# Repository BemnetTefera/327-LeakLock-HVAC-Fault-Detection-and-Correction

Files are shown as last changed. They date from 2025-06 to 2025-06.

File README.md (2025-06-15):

# LeakLock – Smart HVAC Fault Detection & Correction System

**LeakLock** is a low-cost, real-time HVAC monitoring solution that detects air duct leaks and corrects airflow across a three-zone system. Built with an ESP32, distributed sensors, and a web interface, it combines embedded systems, IoT, and sustainable design principles to solve a real-world energy efficiency problem.

---


# 📄 [Full Design Description (Click Here)](description.md)

## 🔧 Features

- 📶 Wi-Fi-enabled ESP32 microcontroller
- 🌡️ Real-time temperature and pressure sensing
- 🌀 Dual fan and motorized damper control
- 🖥️ Custom web interface using HTML, CSS, and JavaScript
- 🔄 OTA (Over-the-Air) updates for remote firmware management
- 🧩 PCB design files for sensor integration
- 📦 Total cost under $50

---

## 📁 Repository Structure

| File/Folder | Description |
|---|---|
| `index.html` | Web interface frontend |
| `style.css` | Styling for the frontend |
| `server.py` | Tornado-based WebSocket server backend |
| `main.cpp` | ESP32 firmware: sensor reading & motor control |
| `wifi_manager.cpp/h` | Wi-Fi connection handler |
| `sensor_final_v1.brd` | PCB board layout (EAGLE) |
| `sensor_final_v1.sch` | PCB schematic (EAGLE) |
| `README.md` | This file 📄 |

---

## ⚙️ How It Works

1. Sensors collect pressure and temperature data from three duct zones.
2. ESP32 processes this data and communicates with a web dashboard over Wi-Fi.
3. Based on detected anomalies (e.g., pressure drop), the system adjusts fans and damper positions to maintain balance.
4. The user can monitor and override controls via the web interface.
5. Updates can be deployed remotely via OTA.

---

## 🚀 Requirements

- ESP32 Dev Module
- TMP102 Temperature Sensor(s)
- LPS25HB Pressure Sensor(s)
- TB6612FNG Dual H-Bridge Motor Driver
- Servo Motor (for damper control)
- 3D-printed or physical duct model (optional)
- Tornado (Python backend)
- EAGLE (for PCB design)

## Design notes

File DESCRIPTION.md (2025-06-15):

# LeakLock: HVAC Fault Detection and Correction System

**Northwestern University**  
**Department of Electrical and Computer Engineering**  
**ELEC_ENG 327: Electronic System Design II**  
**Project Report by Bemnet Tefera – May 2025**

---

## 📑 Table of Contents

1. [Abstract](#abstract)  
2. [Introduction](#introduction)  
3. [Design Requirements and Constraints](#design-requirements-and-constraints)  
4. [Engineering Standards](#engineering-standards)  
5. [Broader Considerations](#broader-considerations)  
6. [Design Description](#design-description)  
   - [System Overview](#system-overview)  
   - [Block Diagram](#block-diagram)  
   - [Firmware and Code](#firmware-and-code)  
   - [3D Printing](#3d-printing)  
   - [PCB Design](#pcb-design)  
7. [Final Product](#final-product)  
8. [Performance and Limitations](#performance-and-limitations)  
9. [Challenges Encountered](#challenges-encountered)  
10. [Planning and Organization](#planning-and-organization)  
11. [Bill of Materials (BOM)](#bill-of-materials-bom)  
12. [Interview Results and Market Research](#interview-results-and-market-research)  
13. [Conclusion](#conclusion)  
14. [References](#references)  

---

## Abstract

LeakLock is a smart, affordable HVAC fault detection system designed to identify duct leaks and airflow inefficiencies in real-time. Built using ESP32 microcontrollers, distributed pressure and temperature sensors, and a web-based dashboard, it enables intelligent zone-based regulation across a three-zone mock HVAC duct. OTA updates, Wi-Fi connectivity, and live dashboard control make it scalable and user-friendly. LeakLock operates under $50 and offers an alternative to expensive commercial systems, making HVAC optimization accessible to both residential and developing regions.

## Introduction

LeakLock aims to solve the often-overlooked problem of HVAC inefficiency due to undetected faults. This embedded system monitors airflow and temperature data, then responds with fan control and damper adjustments to restore balance. The solution uses off-the-shelf hardware and a custom interface built with HTML/CSS/JS, focusing on simplicity and affordability compared to commercial alternatives.

### Problem Statement

HVAC systems lose energy due to hidden inefficiencies like duct leaks and sensor failures. Most current solutions are expensive, require complex setup, and lack real-time response. LeakLock addresses these limitations by offering a modular, responsive, low-cost alternative for multi-zone HVAC diagnostics.

## Design Requirements and Constraints

### Key Requirements
- Multi-zone temperature and pressure monitoring
- Real-time sensor feedback and response
- OTA firmware updates over Wi-Fi
- Live dashboard for monitoring and manual overrides
- Target system cost under $50

### Design Constraints
- Budget limited sensor precision (e.g., low Pa sensitivity in LPS25HB)
- Component integration required space optimization
- I²C channel limits required a multiplexer
- Environmental simulation with 3D printed ducts lacked real-world turbulence/humidity

## Engineering Standards

- Software written in Arduino C++ with modular FreeRTOS tasks
- Sensors used I²C protocol, communication handled via WebSocket (RFC 6455)
- PCB followed best practices in bypassing, grounding, and 3.3V regulation
- Fail-safes included timeout-based actuator shutdowns and startup defaults

## Broader Considerations

LeakLock's accessibility has wide-reaching implications for energy conservation, especially in underserved regions. Its privacy-respecting local data use and intuitive UI encourage widespread adoption. Future improvements could include encryption and authentication for remote access.

## Design Description

### System Overview
- TMP102 (Temp), LPS25HB (Pressure), 5V fans, servos per zone
- ESP32 Wroom-32E controls each zone, communicates via WebSockets
- Web UI supports 3D HVAC model and manual control

### Block Diagram


### Firmware and Code
- Structured around FreeRTOS for modular tasking
- Handles sensor reads, UI communication, actuator control, OTA updates
- Uses TCA I²C MUX to manage multiple sensors per board

### 3D Printing
LeakLock uses a T-shaped 3D printed duct system sealed with aluminum tape to simulate real HVAC airflow. It allows testing of backpressure effects and zone control but lacks full thermal or turbulent fidelity.




### PCB Design
Two iterations were produced:
1. Breakout + breadboard with separate ESP32 (60x70mm)
2. Final compact board (45x50mm) with integrated microcontroller, motor driver, MUX, and indicator LEDs
------------------------------------------------------------------------------------------------------------------------------------------------------
### Final Iteration of Manufatured PCB
<div style="display: flex; gap: 10px;">
  3D Printed Duct 2
   3D Printed Duct 1
</div>
-------------------------------------------------------------------------------------------------------------------------------------------------------

## Final Product

### Initial Goal vs Final Product
- Retained core goal of <$50 cost per module (actual: $16.35)
- UI moved from 3D model to reliable data display
- Dampers functional but not mechanically integrated due to fit challenges
- RTOS replaced loop-based firmware for better parallelism

### Initial Loop based Architecture


### Improved Real Time Operating System Flow


### Final User interface


## Performance and Limitations

- System latency: <150ms round trip
- FreeRTOS improved responsiveness and multitasking
- Sensor precision limited by hardware
- UI does not currently support trend logging or analytics

## Challenges Encountered

- Mechanical issues with damper integration in 3D duct
- ML model failed due to lack of labeled datasets (43.6% error)
- I²C misreads from misinterpreting 16-bit register format
- Early complexity managing multiple sensors and task flows

## Planning and Organization

Project executed over 8 weeks with milestones tracked via Gantt chart. Major tasks included PCB design, mechanical build, UI development, and firmware migration to RTOS.

## Bill of Materials (BOM)

| Component | Quantity | Unit Price | Total |
|---|---|---|---|
| TB6612FNG H-Bridge | 5 | $1.82 | $9.10 |
| TMP102 Temp Sensor | 12 | $0.69 | $8.28 |
| LPS25HB Pressure Sensor  | 12 | $4.62 | $55.44|
| TCA9548A I²C Mux | 5 | $1.17 | $5.85 |
| Passive Components | — | — | ~$10  |
| **Total Cost (approx.)** | | | **$93.26** |

## Interview Results and Market Research

Professionals and renters alike expressed interest in an affordable, intelligent HVAC tool. Market size expected to reach $479M by 2033. Key interview insights emphasized automation, accessibility, cost-efficiency, and security. LeakLock compares favorably to $500–$2000 commercial competitors like Ecobee, Robinair, and INFICON.

## Conclusion

LeakLock brought together hardware, firmware, UI, and real-world design principles into a system that’s scalable and cost-effective. Despite setbacks like sensor limitations and incomplete ML models, it stands as a robust foundation for future HVAC optimization tools. Future directions include cloud integration, mobile apps, better prediction models, and improved mechanical integration.

## References

- Chvala, W. D. (2021). *Duct leakage in residential homes (FY1024)*. University of Florida IFAS Extension. https://edis.ifas.ufl.edu/publication/FY1024  
- Market Growth Reports (2025). *Leak Detection Equipment Market Forecast*. https://www.marketgrowthreports.com/market-reports/leak-detection-equipment-market-111538

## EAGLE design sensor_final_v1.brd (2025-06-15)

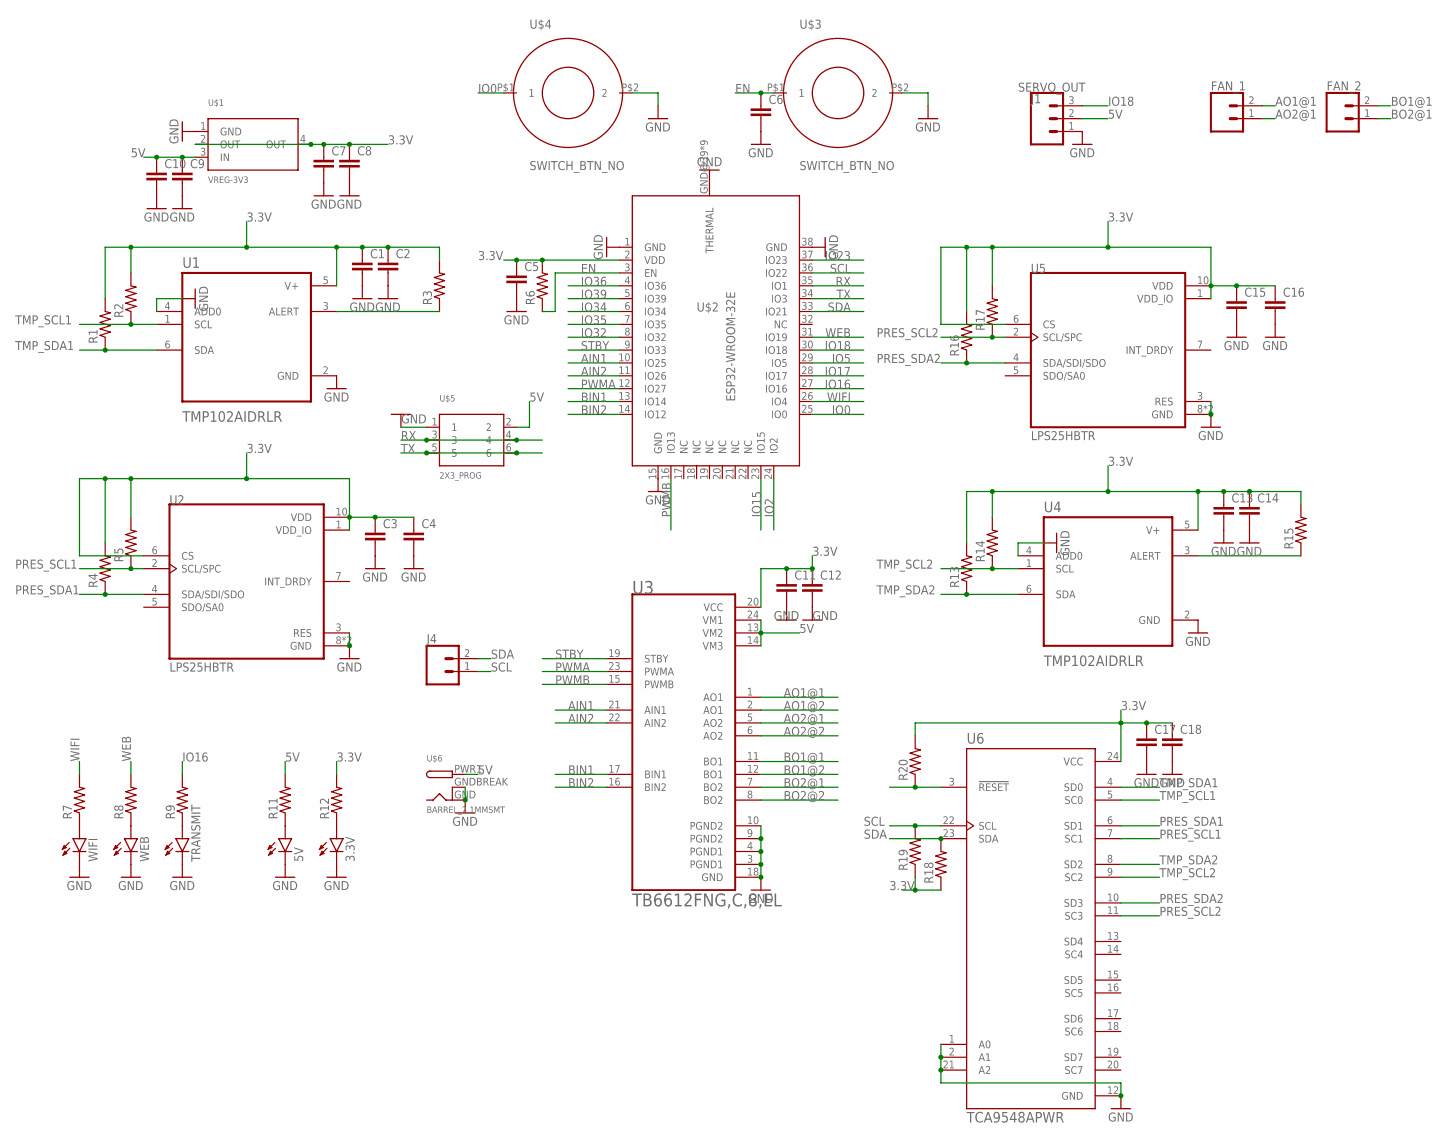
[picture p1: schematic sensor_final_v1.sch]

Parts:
3.3V, 5V: LEDSMT1206; 1206
C1, C2, C3, C4, C5, C6, C7, C8, C9, C10, C11, C12, C13, C14, C15, C16, C17, C18: CAP; 0805
FAN_1, FAN_2: CONN_02; 1X02
J1: SERVO_OUT; 1X03
J4: CONN_02; 1X02
R1, R2, R3, R4, R5, R6, R7, R8, R9, R11, R12, R13, R14, R15, R16, R17, R18, R19, R20: RES; 0805
TRANSMIT: LEDSMT1206; 1206
U1, U4: TMP102AIDRLR; SOT50P160X60-6N
U2, U5: LPS25HBTR; PQFN60P250X250X80-10N
U3: TB6612FNG,C,8,EL; SOP65P760X160-24N
U6: TCA9548APWR; SOP65P640X120-24N
U$1: VREG-3V3; R-PDSO-G4_TI
U$2: ESP32-WROOM-32E
U$3, U$4: SWITCH_BTN_NO; BTN_2
U$5: 2X3_PROG; 2X3_0.1IN
U$6: BARREL_2.1MMSMT; DCJACK_2MM_SMT
WEB: LEDSMT1206; 1206
WIFI: LEDSMT1206; 1206

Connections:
3.3V: C1.1, C2.1, C3.1, C4.1, C5.1, C7.1, C8.1, C11.1, C12.1, C13.1, C14.1, C15.1, C16.1, C17.1, C18.1, R1.2, R2.2, R3.2, R4.2, R5.2, R6.2, R12.2, R13.2, R14.2, R15.2, R16.2, R17.2, R18.1, R19.1, R20.2, U1.5 (V+), U2.1 (VDD_IO), U2.6 (CS), U2.10 (VDD), U3.20 (VCC), U4.5 (V+), U5.1 (VDD_IO), U5.6 (CS), U5.10 (VDD), U6.24 (VCC), U$1.2 (OUT), U$1.4 (OUT), U$2.2 (VDD)
5V: C9.1, C10.1, J1.2, R11.2, U3.13 (VM2), U3.14 (VM3), U3.24 (VM1), U$1.3 (IN), U$5.2, U$6.PWR1 (PWR)
AIN1: U3.21 (AIN1), U$2.10 (IO25)
AIN2: U3.22 (AIN2), U$2.11 (IO26)
AO1@1: FAN_1.2, U3.1 (AO1)
AO1@2: U3.2 (AO1)
AO2@1: FAN_1.1, U3.5 (AO2)
AO2@2: U3.6 (AO2)
BIN1: U3.17 (BIN1), U$2.13 (IO14)
BIN2: U3.16 (BIN2), U$2.14 (IO12)
BO1@1: FAN_2.2, U3.11 (BO1)
BO1@2: U3.12 (BO1)
BO2@1: FAN_2.1, U3.7 (BO2)
BO2@2: U3.8 (BO2)
EN: C6.1, R6.1, U$2.3 (EN), U$3.P$1 (1)
GND: 3.3V.C, 5V.C, C1.2, C2.2, C3.2, C4.2, C5.2, C6.2, C7.2, C8.2, C9.2, C10.2, C11.2, C12.2, C13.2, C14.2, C15.2, C16.2, C17.2, C18.2, J1.1, TRANSMIT.C, U1.2 (GND), U1.4 (ADD0), U2.3 (RES), U2.8 (GND), U2.9 (GND), U3.3 (PGND1), U3.4 (PGND1), U3.9 (PGND2), U3.10 (PGND2), U3.18 (GND), U4.2 (GND), U4.4 (ADD0), U5.3 (RES), U5.8 (GND), U5.9 (GND), U6.1 (A0), U6.2 (A1), U6.12 (GND), U6.21 (A2), U$1.1 (GND), U$2.1 (GND), U$2.15 (GND), U$2.38 (GND), U$2.GND@39 (THERMAL), U$2.GND@40 (THERMAL), U$2.GND@41 (THERMAL), U$2.GND@42 (THERMAL), U$2.GND@43 (THERMAL), U$2.GND@44 (THERMAL), U$2.GND@45 (THERMAL), U$2.GND@46 (THERMAL), U$2.GND@47 (THERMAL), U$3.P$2 (2), U$4.P$2 (2), U$5.1, U$6.GND, U$6.GNDBREAK, WEB.C, WIFI.C
IO0: U$2.25 (IO0), U$4.P$1 (1)
IO2: U$2.24 (IO2)
IO5: U$2.29 (IO5)
IO15: U$2.23 (IO15)
IO16: R9.2, U$2.27 (IO16)
IO17: U$2.28 (IO17)
IO18: J1.3, U$2.30 (IO18)
IO23: U$2.37 (IO23)
IO32: U$2.8 (IO32)
IO34: U$2.6 (IO34)
IO35: U$2.7 (IO35)
IO36: U$2.4 (IO36)
IO39: U$2.5 (IO39)
unnamed: R20.1, U6.3 (!RESET)
unnamed: R3.1, U1.3 (ALERT)
unnamed: R7.1, WIFI.A
unnamed: R8.1, WEB.A
unnamed: R9.1, TRANSMIT.A
unnamed: 5V.A, R11.1
unnamed: 3.3V.A, R12.1
unnamed: R15.1, U4.3 (ALERT)
PRES_SCL1: R5.1, U2.2 (SCL/SPC), U6.7 (SC1)
PRES_SCL2: R17.1, U5.2 (SCL/SPC), U6.11 (SC3)
PRES_SDA1: R4.1, U2.4 (SDA/SDI/SDO), U6.6 (SD1)
PRES_SDA2: R16.1, U5.4 (SDA/SDI/SDO), U6.10 (SD3)
PWMA: U3.23 (PWMA), U$2.12 (IO27)
PWMB: U3.15 (PWMB), U$2.16 (IO13)
RX: U$2.35 (IO1), U$5.3, U$5.4
SCL: J4.1, R19.2, U6.22 (SCL), U$2.36 (IO22)
SDA: J4.2, R18.2, U6.23 (SDA), U$2.33 (IO21)
STBY: U3.19 (STBY), U$2.9 (IO33)
TMP_SCL1: R2.1, U1.1 (SCL), U6.5 (SC0)
TMP_SCL2: R14.1, U4.1 (SCL), U6.9 (SC2)
TMP_SDA1: R1.1, U1.6 (SDA), U6.4 (SD0)
TMP_SDA2: R13.1, U4.6 (SDA), U6.8 (SD2)
TX: U$2.34 (IO3), U$5.5, U$5.6
WEB: R8.2, U$2.31 (IO19)
WIFI: R7.2, U$2.26 (IO4)

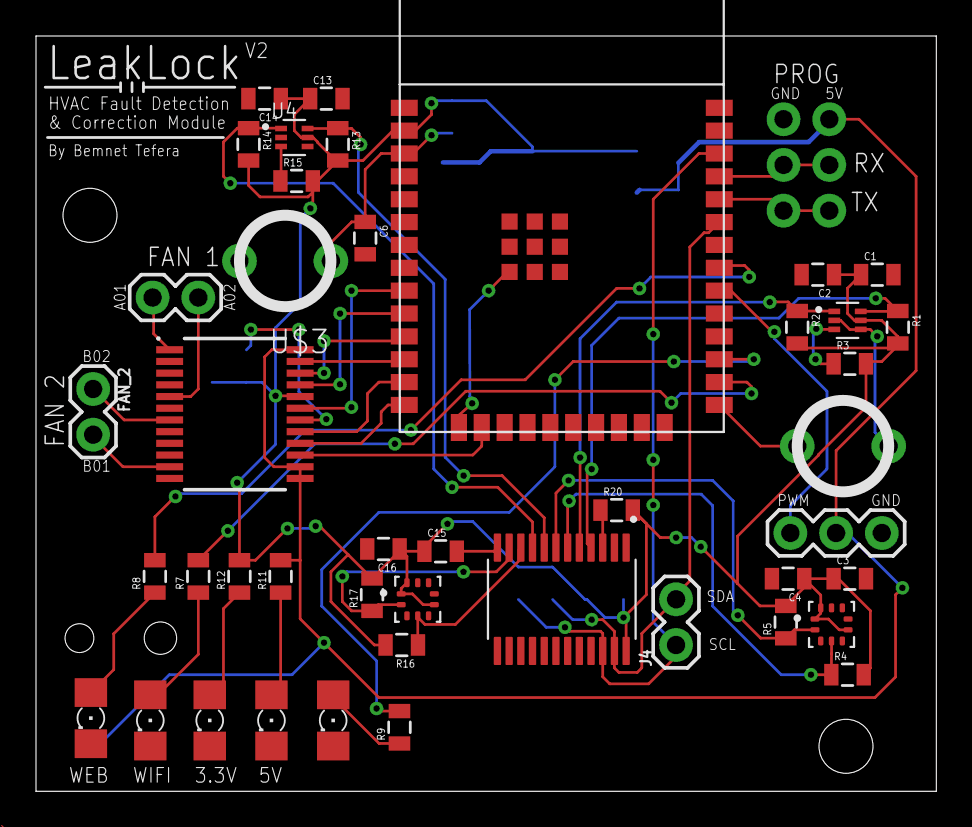
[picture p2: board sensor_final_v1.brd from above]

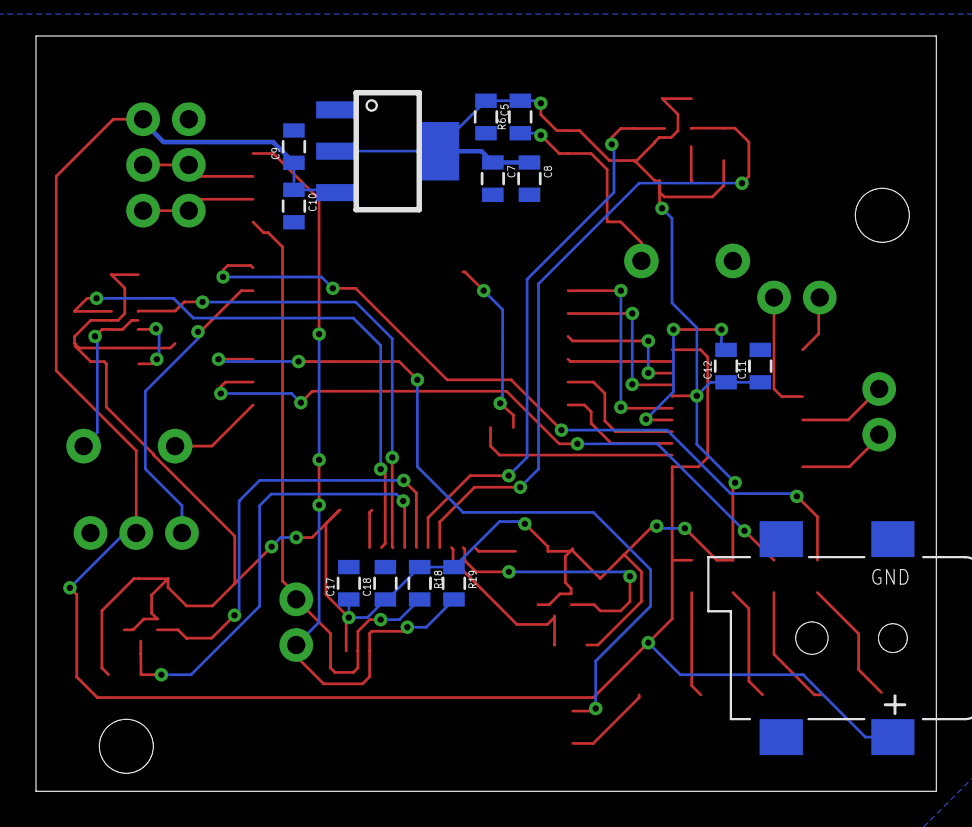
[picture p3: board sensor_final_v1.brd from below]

Board: 2 copper layers, 50.0 x 42.0 mm, 58 parts (14 on the bottom side), 40 nets.

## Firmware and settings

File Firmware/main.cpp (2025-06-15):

// ========== ESP32 HVAC FIRMWARE (Rewritten) ==========
#include <Arduino.h>
#include <Wire.h>
#include <WebSocketsClient.h>
#include <ArduinoJson.h>
#include "wifi_manager.h"

#define DEVICE_ID "zone2"  // Change this per ESP32: zone1, zone2, zone3
#define TMP102_ADDR 0x48
#define LPS25HB_ADDR 0x5D
#define TCA_ADDR 0x70

// Fan control
#define AIN1 25
#define AIN2 26
#define PWMA 27
#define BIN1 14
#define BIN2 12
#define PWMB 13
#define STBY 33
#define PWM_CHANNEL_A 0
#define PWM_CHANNEL_B 1
#define PWM_FREQ 1000
#define PWM_RES 8

// Servo
#define SERVO_PIN 18
#define PWM_CHANNEL_SERVO 2
#define SERVO_FREQ 50

// LEDs
#define WIFI_LED 4
#define WS_LED 19

// WebSocket target
const char* websocket_host = "192.168.12.211";
const uint16_t websocket_port = 8888;
const char* websocket_path = "/ws_esp32";

// State
int damperAngle = 90, lastDamperAngle = -1;
bool fanForward = true;
uint8_t fanSpeed = 128;
bool wifiConnected = false;
bool wsConnected = false;

WebSocketsClient webSocket;

// Tasks
TaskHandle_t h_sensorTask, h_webSocketTask, h_damperTask;

void tcaSelect(uint8_t channel) {
  if (channel > 7) return;
  Wire.beginTransmission(TCA_ADDR);
  Wire.write(1 << channel);
  Wire.endTransmission();
}

void applyFanSettings() {
  digitalWrite(STBY, HIGH);
  if (fanForward) {
    digitalWrite(BIN1, LOW); digitalWrite(BIN2, LOW); ledcWrite(PWM_CHANNEL_B, 0);
    digitalWrite(AIN1, HIGH); digitalWrite(AIN2, LOW); ledcWrite(PWM_CHANNEL_A, fanSpeed);
  } else {
    digitalWrite(AIN1, LOW); digitalWrite(AIN2, LOW); ledcWrite(PWM_CHANNEL_A, 0);
    digitalWrite(BIN1, HIGH); digitalWrite(BIN2, LOW); ledcWrite(PWM_CHANNEL_B, fanSpeed);
  }
}

void webSocketEvent(WStype_t type, uint8_t * payload, size_t length) {
  if (type == WStype_CONNECTED) {
    wsConnected = true;
    // Send handshake with device_id
    DynamicJsonDocument doc(64);
    doc["device_id"] = DEVICE_ID;
    String handshake;
    serializeJson(doc, handshake);
    webSocket.sendTXT(handshake);
  }
  else if (type == WStype_DISCONNECTED) wsConnected = false;

  if (type == WStype_TEXT) {
    DynamicJsonDocument doc(256);
    DeserializationError error = deserializeJson(doc, payload);
    if (error || !doc.containsKey("control")) return;
    if (doc["device_id"] != DEVICE_ID) return;

    String control = doc["control"];
    if (control == "speed") fanSpeed = doc["value"];
    else if (control == "direction") {
    String direction = doc["value"].as<String>();
    fanForward = (direction == "forward");
    } else if (control == "angle") damperAngle = constrain(doc["value"], 0, 180);
    applyFanSettings();
  }
}

float readTemperature(uint8_t ch) {
  tcaSelect(ch);
  Wire.beginTransmission(TMP102_ADDR);
  Wire.write(0x00);
  if (Wire.endTransmission() != 0) return 999;
  Wire.requestFrom(TMP102_ADDR, 2);
  if (Wire.available() < 2) return 999;
  int16_t raw = (Wire.read() << 4) | (Wire.read() >> 4);
  if (raw > 0x7FF) raw |= 0xF000;
  return raw * 0.0625 - 7.8;
}

float readPressure(uint8_t ch) {
  tcaSelect(ch);
  Wire.beginTransmission(LPS25HB_ADDR);
  Wire.write(0x28 | 0x80);
  if (Wire.endTransmission() != 0) return 999;
  Wire.requestFrom(LPS25HB_ADDR, 3);
  if (Wire.available() < 3) return 999;
  uint32_t raw = Wire.read();
  raw |= (Wire.read() << 8);
  raw |= (Wire.read() << 16);
  return raw / 4096.0 + 57;
}

void setServoAngle(int angle) {
  uint32_t duty = map(angle, 0, 180, 1638, 8192);
  ledcWrite(PWM_CHANNEL_SERVO, duty);
}

void sensorTask(void* pvParams) {
  while (true) {
    float t1 = readTemperature(0), t2 = readTemperature(2);
    float p1 = readPressure(1), p2 = readPressure(3);
    float avgT = (t1 + t2) / 2.0;
    float avgP = (p1 + p2) / 2.0;

    DynamicJsonDocument doc(256);
    doc["device_id"] = DEVICE_ID;
    doc["temp"] = avgT;
    doc["pressure"] = avgP;
    doc["fan_speed"] = fanSpeed;
    doc["fan_direction"] = fanForward ? "forward" : "reverse";
    doc["damper_angle"] = damperAngle;

    String msg;
    serializeJson(doc, msg);
    if (webSocket.isConnected()) webSocket.sendTXT(msg);
    vTaskDelay(500 / portTICK_PERIOD_MS);
  }
}

void webSocketTask(void* pvParams) {
  while (true) {
    webSocket.loop();
    handleOTA();
    vTaskDelay(50 / portTICK_PERIOD_MS);
  }
}

void damperTask(void* pvParams) {
  while (true) {
    if (abs(damperAngle - lastDamperAngle) >= 2) {
      setServoAngle(damperAngle);
      lastDamperAngle = damperAngle;
    }
    vTaskDelay(100 / portTICK_PERIOD_MS);
  }
}

void ledTask(void* pvParams) {
  unsigned long prevMillisWiFi = millis();
  unsigned long prevMillisWS = millis();
  bool wifiLedState = false;
  bool wsLedState = false;

  while (true) {
    unsigned long now = millis();

    // WIFI_LED: toggle every 125ms (2 times per second)
    if (now - prevMillisWiFi >= 1000) {
      prevMillisWiFi = now;
      wifiLedState = !wifiLedState;
      digitalWrite(WIFI_LED, wifiLedState);
    }

    // WS_LED: toggle every 250ms (1/4 second)
    if (now - prevMillisWS >= 250) {
      prevMillisWS = now;
      wsLedState = !wsLedState;
      digitalWrite(WS_LED, wsLedState);
    }

    vTaskDelay(10 / portTICK_PERIOD_MS);  // Prevent busy loop
  }
}


void setup() {
  Serial.begin(115200);
  Wire.begin(21, 22);
  pinMode(AIN1, OUTPUT); pinMode(AIN2, OUTPUT); pinMode(PWMA, OUTPUT);
  pinMode(BIN1, OUTPUT); pinMode(BIN2, OUTPUT); pinMode(PWMB, OUTPUT);
  pinMode(STBY, OUTPUT); digitalWrite(STBY, HIGH);
  pinMode(WIFI_LED, OUTPUT); pinMode(WS_LED, OUTPUT);

  ledcSetup(PWM_CHANNEL_A, PWM_FREQ, PWM_RES); ledcAttachPin(PWMA, PWM_CHANNEL_A);
  ledcSetup(PWM_CHANNEL_B, PWM_FREQ, PWM_RES); ledcAttachPin(PWMB, PWM_CHANNEL_B);
  ledcSetup(PWM_CHANNEL_SERVO, SERVO_FREQ, 16); ledcAttachPin(SERVO_PIN, PWM_CHANNEL_SERVO);
  setServoAngle(damperAngle);
  applyFanSettings();

  for (int ch : {1, 3}) {
    tcaSelect(ch);
    Wire.beginTransmission(LPS25HB_ADDR);
    Wire.write(0x20); Wire.write(0b11000000); Wire.endTransmission();
  }

  printMacAddress();
  connectToWiFiAndStartOTA();
  wifiConnected = true;

  webSocket.begin(websocket_host, websocket_port, websocket_path);
  webSocket.onEvent(webSocketEvent);
  webSocket.setReconnectInterval(5000);

  xTaskCreatePinnedToCore(sensorTask,    "Sensor",    4096, NULL, 2, &h_sensorTask,    1);
  xTaskCreatePinnedToCore(webSocketTask, "WebSocket", 2048, NULL, 1, &h_webSocketTask, 1);
  xTaskCreatePinnedToCore(damperTask,    "Damper",    2048, NULL, 1, &h_damperTask,    1);
  xTaskCreatePinnedToCore(ledTask,       "LED",       1024, NULL, 1, NULL,             0);
}

void loop() {}

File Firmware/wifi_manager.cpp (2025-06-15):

#include <WiFi.h>
#include <WebServer.h>
#include <ElegantOTA.h>

extern "C" {
  #include "esp_wpa2.h"
}

// #define WIFI_NU
#define WIFI_REGULAR
// #define WIFI_OPEN

#if defined(WIFI_REGULAR)
const char* ssid = "Addaskjis";
const char* password = "ykjbnx@0718askj?";

#elif defined(WIFI_OPEN)
const char* ssid = "REPLACE_WITH_YOUR_SSID";

#elif defined(WIFI_NU)

#endif

WebServer server(80);

void printMacAddress() {
  Serial.println();
  Serial.print("ESP32 MAC: ");
  Serial.println(WiFi.macAddress());
}

void connectToWiFiAndStartOTA() {
  WiFi.mode(WIFI_STA);
  WiFi.disconnect(true);
  delay(100);

#if defined(WIFI_REGULAR)
  Serial.println("Connecting to regular network...");
  WiFi.begin(ssid, password);

#elif defined(WIFI_OPEN)
  Serial.println("Connecting to open network...");
  WiFi.begin(ssid);

#elif defined(WIFI_NU)
  Serial.println("Connecting to WPA2-Enterprise (Device Northwestern)...");
  esp_wifi_sta_wpa2_ent_set_identity((uint8_t *)eap_anonymous_id, strlen(eap_anonymous_id));
  esp_wifi_sta_wpa2_ent_set_username((uint8_t *)eap_id, strlen(eap_id));
  esp_wifi_sta_wpa2_ent_set_password((uint8_t *)eap_password, strlen(eap_password));
  esp_wifi_sta_wpa2_ent_enable();
  WiFi.begin(ssid);
#endif

  Serial.print("Connecting");
  int tries = 0;
  while (WiFi.status() != WL_CONNECTED && tries++ < 40) {
    delay(500);
    Serial.print(".");
  }

  if (WiFi.status() == WL_CONNECTED) {
    Serial.println("\n✅ \t  Connected!");
    Serial.print("IP Address: ");
    Serial.println(WiFi.localIP());

    // Setup OTA
    server.on("/", []() {
      server.send(200, "text/plain", "Hello! Head to /update to upload new firmware.");
    });

    ElegantOTA.begin(&server);
    server.begin();

    Serial.println("\n✅ \t OTA Server started.");
    Serial.print("➡ Visit http://");
    Serial.print(WiFi.localIP());
    Serial.println("/update to upload firmware.");
  } else {
    Serial.println("\n❌ \t  Failed to connect.");
  }
}

void handleOTA() {
  server.handleClient();
}

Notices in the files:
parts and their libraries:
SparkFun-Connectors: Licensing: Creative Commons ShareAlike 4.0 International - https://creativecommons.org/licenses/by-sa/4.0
